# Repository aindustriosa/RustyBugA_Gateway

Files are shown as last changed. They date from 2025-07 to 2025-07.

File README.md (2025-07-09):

# WiFi Serial Gateway for the [RustyBugA](https://github.com/aindustriosa/RustyBugA-board#)

Firmware and tools for a Seeed Studio XIAO C3 based serial gateway that uses WiFi as wireless interface.

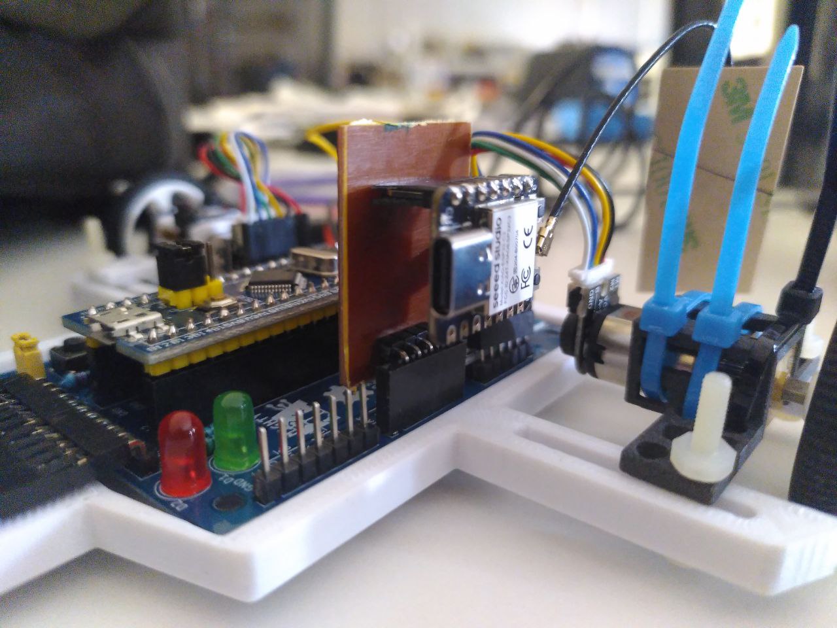
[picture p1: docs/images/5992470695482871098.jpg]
Description


# Usage
## Hardware connections
TBD

## Connect from the PC using USB (like an FTDI)
> Remember to remove the jumper when the USB cable is not connected.

Make all the connections and:
```
picocom /dev/ttyACM3 -b 115200
```
This interface also prints some internal logs from the gateway (like it's IP address at start).

## Connect from the PC using netcat (like an FTDI but wireless!)
> Remember to use the jumper when the USB cable is not connected.

Connect the PC to the same network as the gateway and use the mDNS name to create a connection:
```
nc -u ${MDNS_NAME}.local 1234
```
now data can be exchanged with the robot.

If you don't know the MDNS_NAME, it is printed over the USB link at start.

## Connect from the PC using tools
TBD

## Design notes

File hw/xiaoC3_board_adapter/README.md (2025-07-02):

# Tools

## PCB design, gerber files creation: KiCAD
Version 9
https://docs.kicad.org/9.0/en/getting_started_in_kicad/getting_started_in_kicad.html

## Gerber to png
https://gerber2png.fablabkerala.in/
https://git.fablabkerala.in/midlaj/gerber2png/-/wikis/home

## PNG to Gcode
https://modsproject.org/

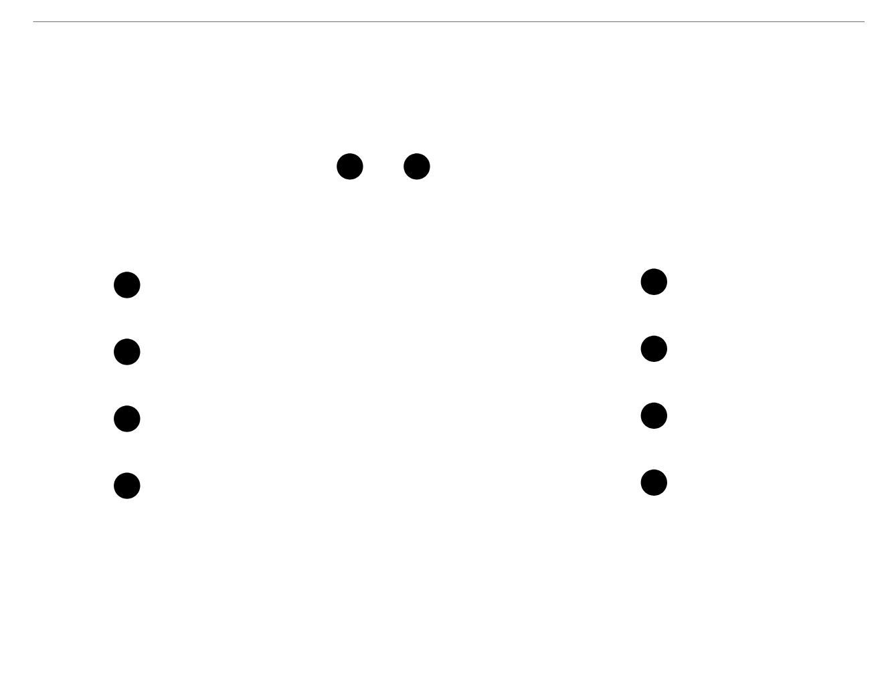
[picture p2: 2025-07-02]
hw/xiaoC3_board_adapter/pngs_and_gcodes/drills_top_layer_1.png

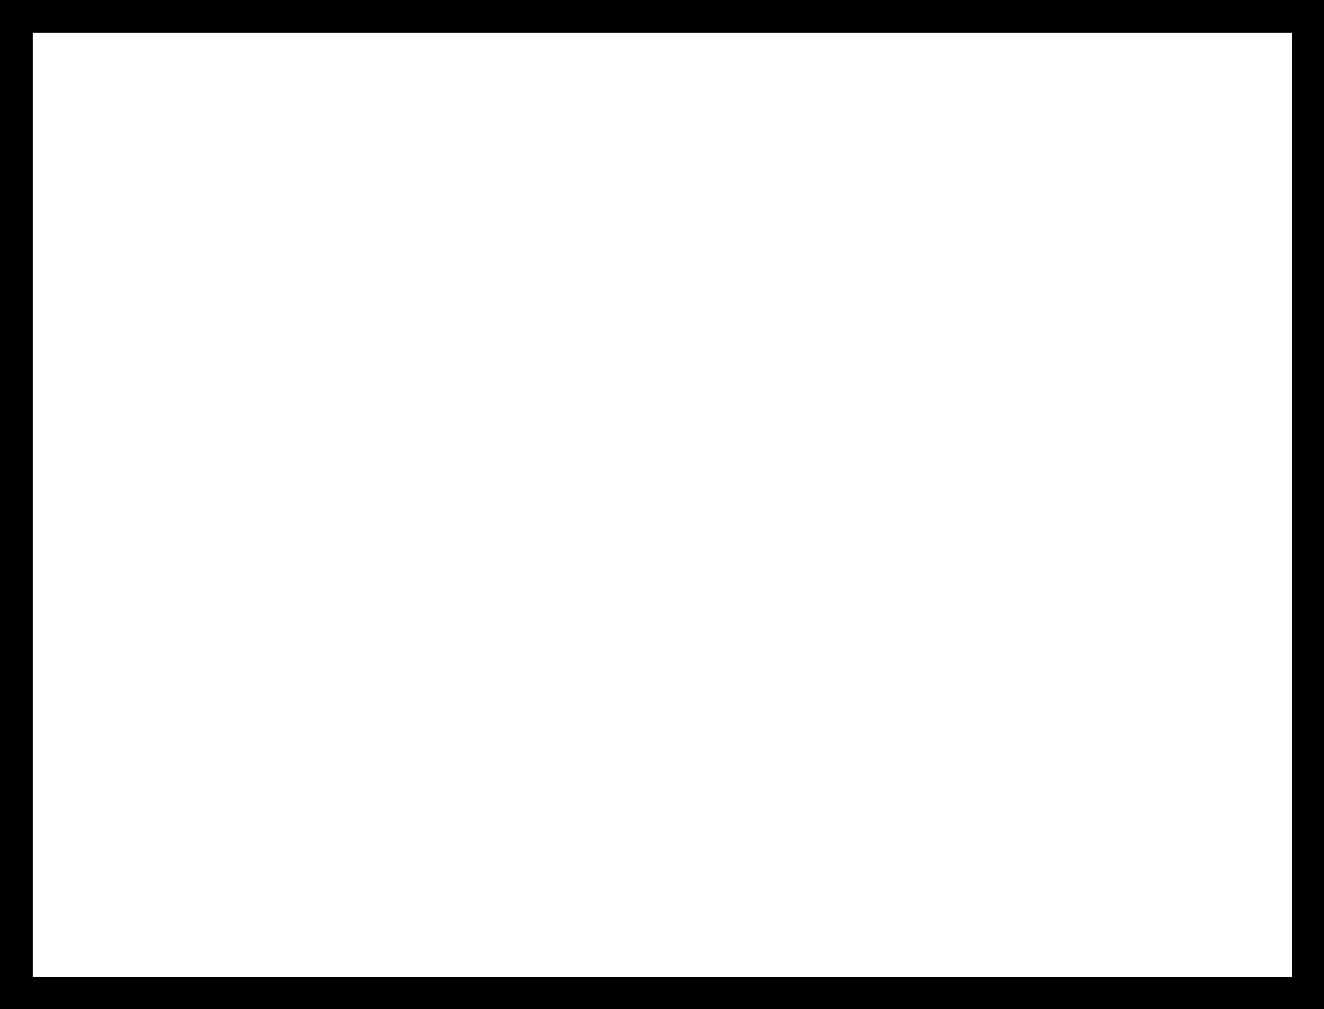
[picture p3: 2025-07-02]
hw/xiaoC3_board_adapter/pngs_and_gcodes/outline_top_layer_2.png

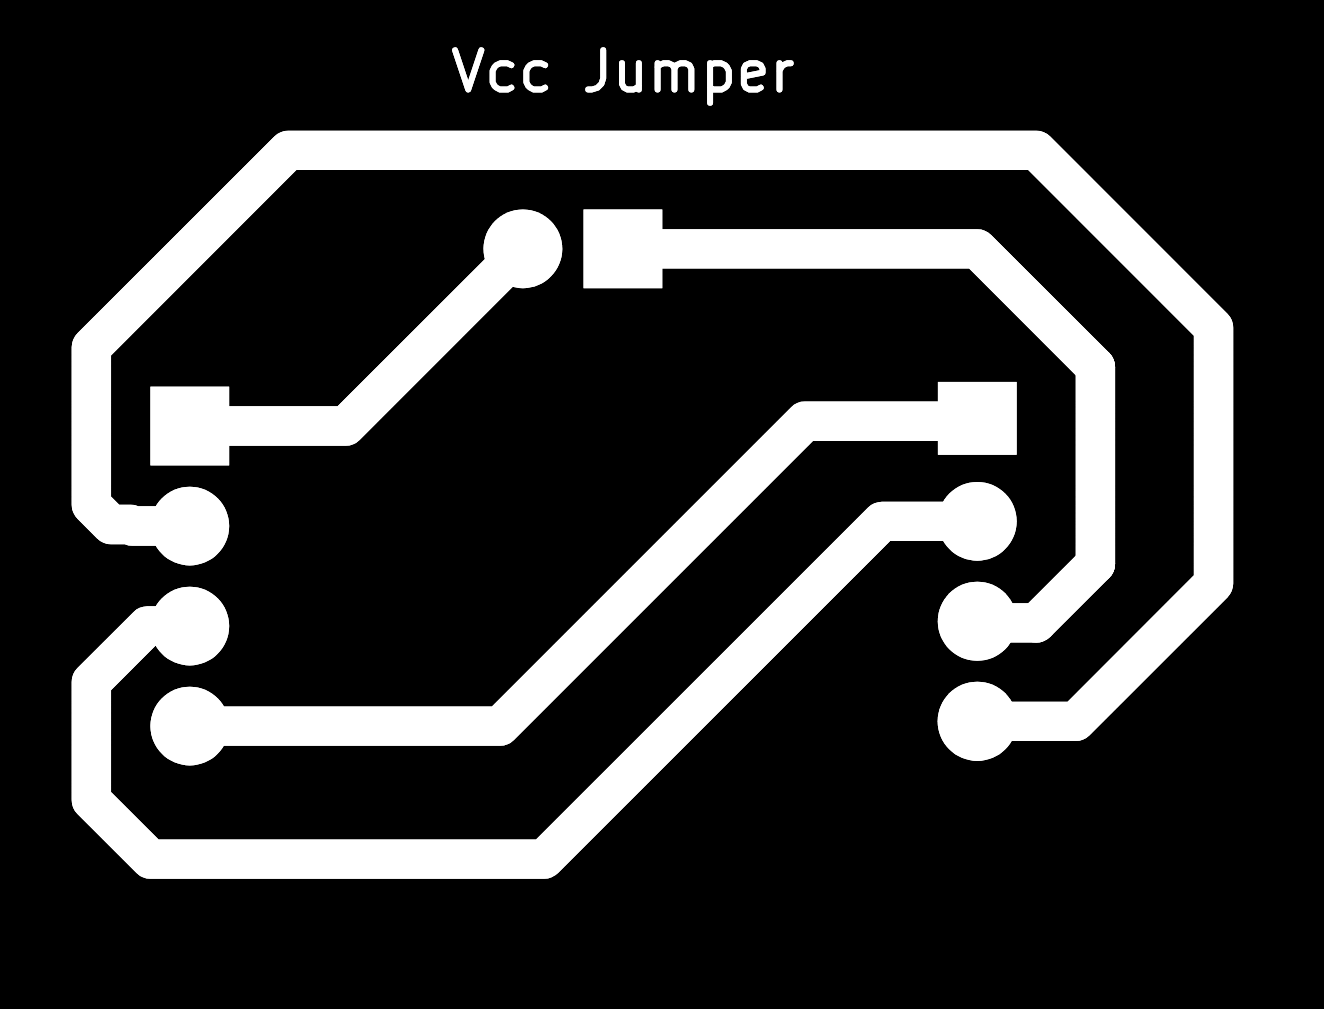
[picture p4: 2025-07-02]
hw/xiaoC3_board_adapter/pngs_and_gcodes/traces_top_layer_0.png

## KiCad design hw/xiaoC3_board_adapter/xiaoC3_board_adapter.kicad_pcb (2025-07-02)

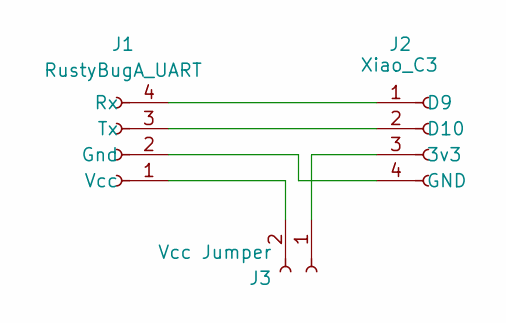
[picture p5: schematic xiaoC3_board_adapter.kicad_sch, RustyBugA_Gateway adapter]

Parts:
J1: RustyBugA_UART; PinHeader_1x04_P2.54mm_Vertical
J2: Xiao_C3; PinHeader_1x04_P2.54mm_Vertical
J3: Vcc Jumper; PinSocket_1x02_P2.54mm_Vertical

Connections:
unnamed: J1.2 (Gnd), J2.4 (GND)
unnamed: J1.4 (Rx), J2.1 (D9)
unnamed: J1.3 (Tx), J2.2 (D10)
unnamed: J1.1 (Vcc), J3.2
unnamed: J2.3 (3v3), J3.1

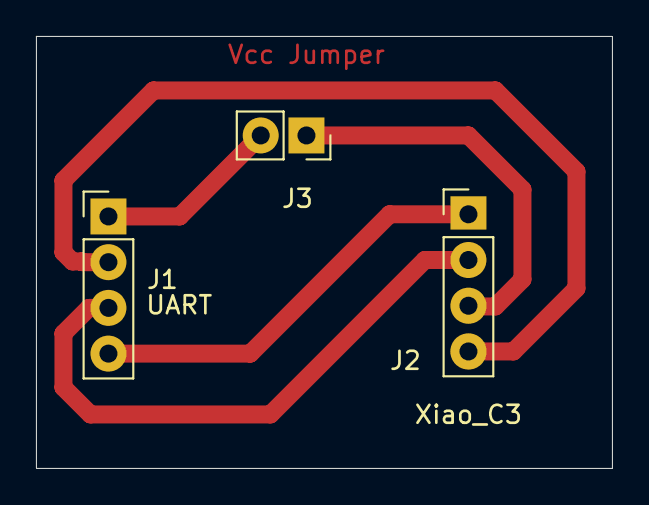
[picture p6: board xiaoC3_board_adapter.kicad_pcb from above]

Board: 2 copper layers, 32.0 x 24.0 mm, 3 parts (0 on the bottom side), 5 nets.

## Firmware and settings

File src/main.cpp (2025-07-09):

/// Wifi UDP server that acts as a serial port gateway
///
/// Connections:
///  - Wifi: UDP connection for users
///  - Serial (USB serial): Also for user side
///  - Serial0 (Hardware serial): for the RustyBugA side

#include <Arduino.h>
#include <WiFi.h>
#include <ESPmDNS.h>

// Wifi credentials
// secrets.hpp should define WIFI_SSID, WIFI_PASS, and MDNS_HOSTNAME.
// check secrets_example.hpp for an example
#include "secrets.hpp"
char *ssid = WIFI_SSID;
char *pass = WIFI_PASS;
char *mdns_hostname = MDNS_HOSTNAME;

// Udp server setup
WiFiUDP udp;
const unsigned int localUdpPort = SERVER_PORT;
uint8_t incomingPacket[255];
static IPAddress lastRemoteIP = IPAddress(0, 0, 0, 0);
static uint16_t lastRemotePort = 0;

// Serial port setup
// https://forum.seeedstudio.com/t/how-to-use-serial1-with-xiao-esp32c3/266306/5
HardwareSerial Serial_0(0);

void setup()
{
  // Configure the serial port
  Serial.begin(115200);
  while (!Serial)
  {
    ; // Wait for the serial port to connect. Needed for native USB port only
  }

  // Connect to Wi-Fi
  WiFi.begin(ssid, pass);
  Serial.print("Connecting to WiFi");
  while (WiFi.status() != WL_CONNECTED)
  {
    delay(500);
    Serial.print(".");
  }
  Serial.print("\nConnected to WiFi with ssid: ");
  Serial.println(ssid);
  Serial.print("IP address: ");
  Serial.println(WiFi.localIP());

  // Initialize mDNS
  if (!MDNS.begin(mdns_hostname))
  { // "esp32" will be the hostname (esp32.local)
    Serial.println("Error starting mDNS");
  }
  else
  {
    Serial.print("mDNS responder started with name: ");
    Serial.println(mdns_hostname);
  }

  // Start the UDP server
  udp.begin(localUdpPort);
  Serial.printf("UDP server started at port %d\n", localUdpPort);

  // Initialize Serial_1 for UART1
  Serial_0.begin(115200, SERIAL_8N1, D9, D10);
}

void loop()
{
  // 1. Receive UDP and send to Serial_0
  {
    int packetSize = udp.parsePacket();
    if (packetSize)
    {
      int len = udp.read(incomingPacket, 255);
      if (len > 0)
      {
        Serial_0.write(incomingPacket, len);
      }
      // Save remote IP/port for replies
      lastRemoteIP = udp.remoteIP();
      lastRemotePort = udp.remotePort();
    }
  }

  // 2. Read Serial_0 and send to last UDP client and Serial
  while (Serial_0.available() > 0)
  {
    uint8_t buf[128];
    int n = Serial_0.readBytes(buf, sizeof(buf));

    Serial.write(buf, n);

    if (lastRemotePort != 0)
    {
      udp.beginPacket(lastRemoteIP, lastRemotePort);
      udp.write(buf, n);
      udp.endPacket();
    }
  }

  // 3. Read Serial and send to Serial_0
  while (Serial.available() > 0)
  {
    uint8_t buf[128];
    int n = Serial.readBytes(buf, sizeof(buf));
    Serial_0.write(buf, n);
  }

  delay(1);
}

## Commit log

2025-06-25 Add first version of the adaptation board
    [xiaoC3_board_adapter.kicad_pcb, xiaoC3_board_adapter.kicad_sch]
2025-07-02 Update PCB design and generate gcodes for first working version
    [xiaoC3_board_adapter.kicad_pcb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]
